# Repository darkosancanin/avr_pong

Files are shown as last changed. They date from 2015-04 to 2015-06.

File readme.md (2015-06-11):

### Overview 
ATmega328 based implementation of the classic game PONG with hardware design. The implementation of the game is a one player game with the ability to choose the skill level for the computer AI. The user paddle input control in hardware is done via a potentiometer with the TV and audio signal being output via a RCA connector and the video encoded using the PAL standard.

### PAL Signal Overview
- The PAL TV signal in the game is generated completely by the TVOut Arduino library (https://code.google.com/p/arduino-tvout/). The overview below is purely for the sake of learning.
- PAL (Phase Alternating Line) requires 625 scanlines to create one image on the screen.
- Not all 625 lines can be seen, some are used for sync pulses (and later for teletext etc), ~576 lines are visible.
- The picture is drawn one half at a time (thus the Alternating part in the name), all even lines are drawn first, then the next cycle will display all odd lines and so on. 
- Voltage levels are used to determine shades of between white and black it will render, black = 0.3V and white = 1V. (Color signal is generated differently, not covered here.)
- A voltage ladder is created by using a 470 Ohm and a 1K Ohm resistor to generate the two required voltage levels.
- Each scan line takes 64us (microseconds) to render. 12us sync signals, then 52us for the image signals.
- The vertical frequency is 50Hz, so the screen is updated with 50 half images per second, which is 25 full images per second. 
- See more at http://en.wikipedia.org/wiki/PAL

### Implementation Overview
- The game implementation is based on the code for the Pong game that is part of the Video Game Shield from Wayne and Layne (http://www.wayneandlayne.com/projects/video-game-shield/).
- I made it a one player game with very basic AI for the computer and added 3 skill levels to choose from.
- Other added features include: ability to pause, 'you won' or 'you lost' screens along with self promoting introduction screens.
- The user paddle changes sizes based on the skill level chosen.
- The ball direction when hit is based on where the ball hits the paddle, hitting the ball on the middle of the paddle will send it back in a straight line but hitting the far edges of the paddle will send the ball back at a much sharper angle.
- For the computer AI, the computer paddle moves one pixel closer in the direction of the ball every loop cycle but based on the skill level chosen it has a variable delay in reaction (it doesn't start moving until the ball is x pixels away from it). Another variable between skill levels is the 'loss of concentration' of the computer, basically the computer will not move its paddle every x amount of horizontal pixels that the ball moves across (implemented via the computer_loss_of_concentration_modulo_value variable).
- The TV signal generated is PAL and is purely implemented via TVOut Arduino library (https://code.google.com/p/arduino-tvout/). The resolution used is 120 x 96 pixels.
- The user paddle position is controlled by a analog to digital conversion reading from a 10K Ohm potentiometer.

### Schematic
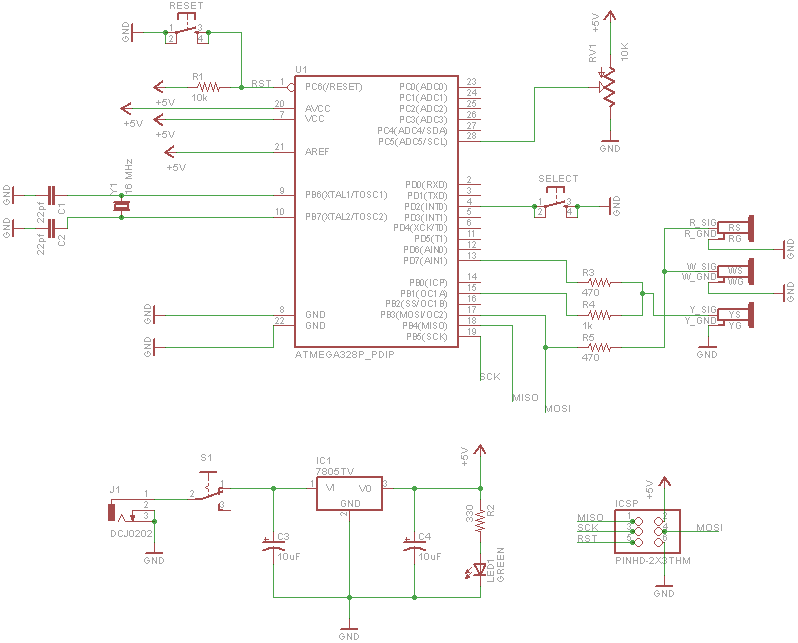
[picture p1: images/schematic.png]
Schematic


### Breadboard
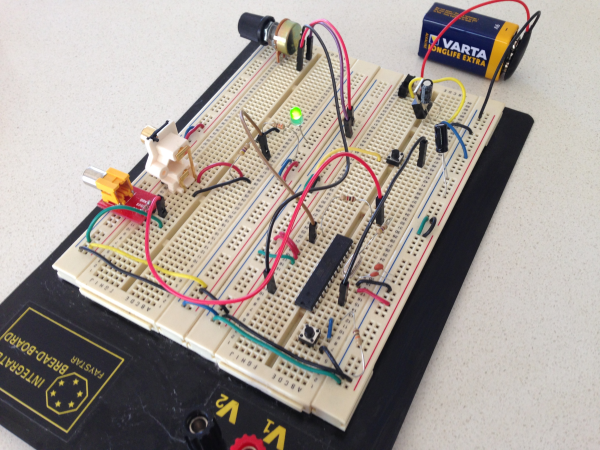
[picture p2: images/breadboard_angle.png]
Angled View


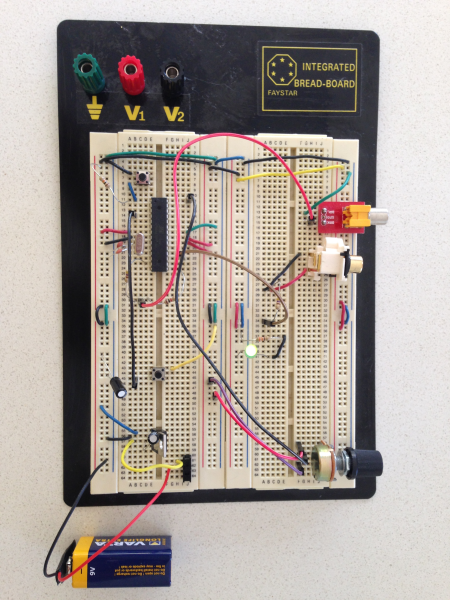
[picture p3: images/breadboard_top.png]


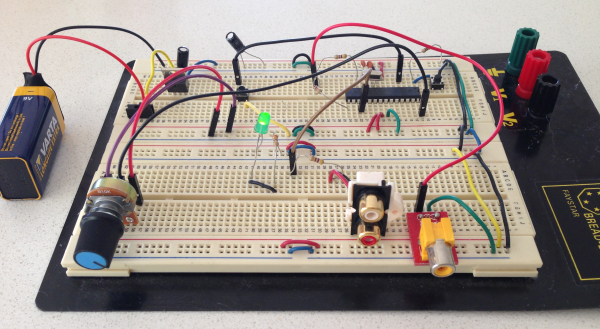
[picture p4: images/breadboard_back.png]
Back View


### TV
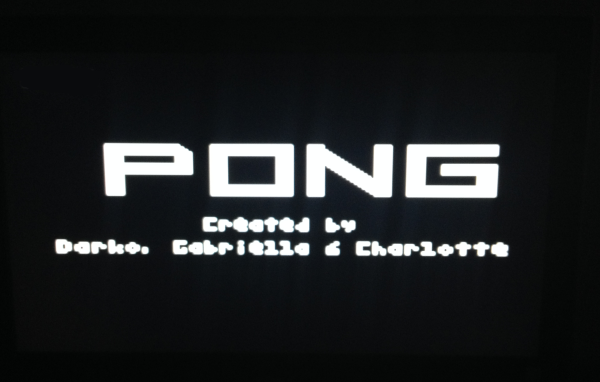
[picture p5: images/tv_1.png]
Introduction Screen


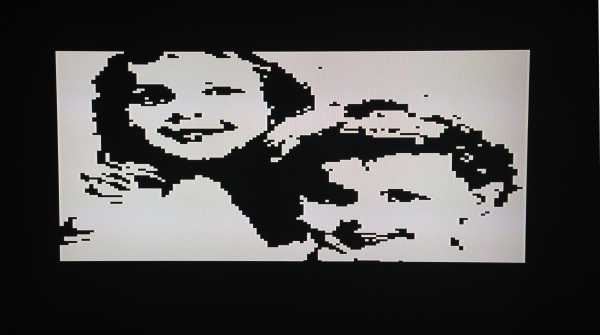
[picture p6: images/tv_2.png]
Introduction Screen Two


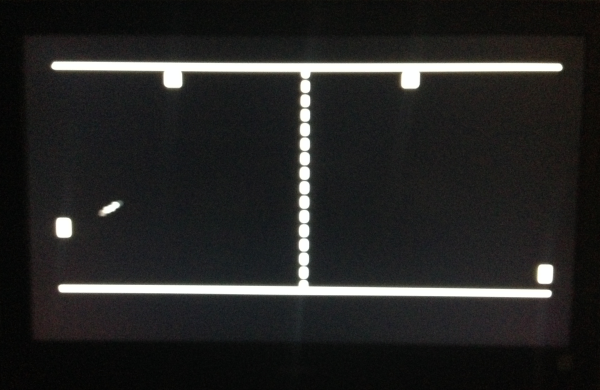
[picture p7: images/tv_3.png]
Game Play


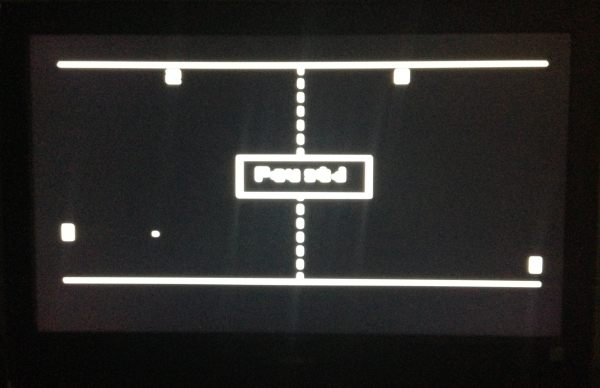
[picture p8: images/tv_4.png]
Paused Screen


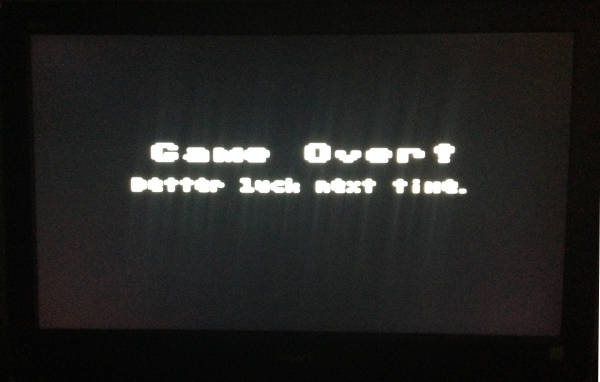
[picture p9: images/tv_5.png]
Game Over Screen


### PCB Layout
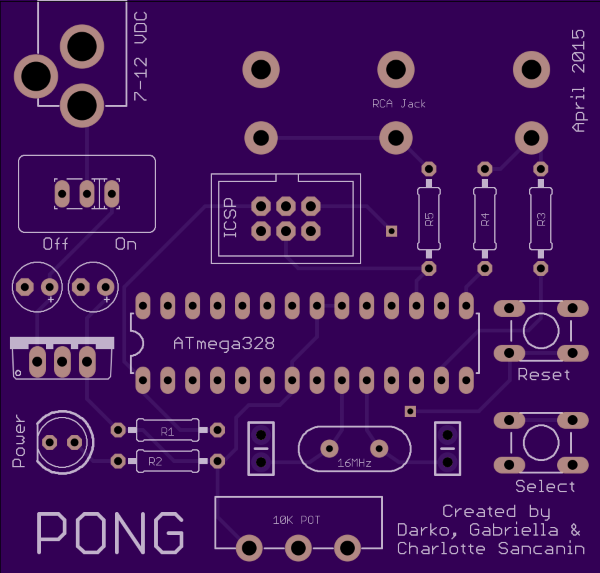
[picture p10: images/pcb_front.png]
Top


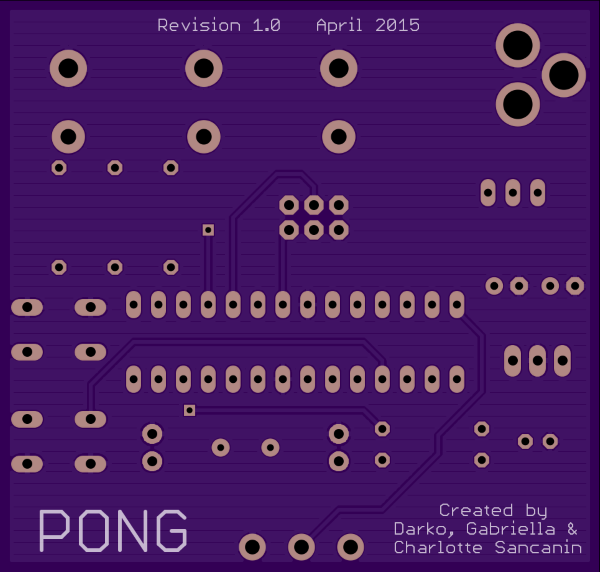
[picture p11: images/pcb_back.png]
Bottom


### Final Product
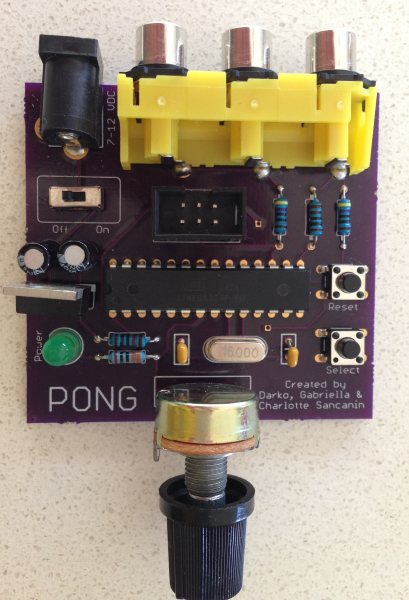
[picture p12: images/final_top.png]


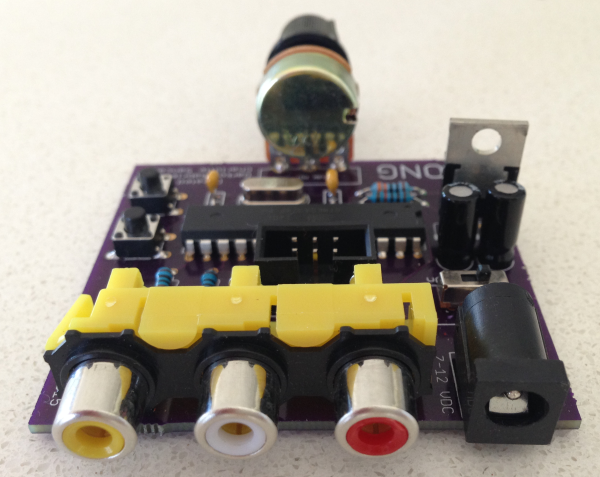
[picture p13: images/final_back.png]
Back View


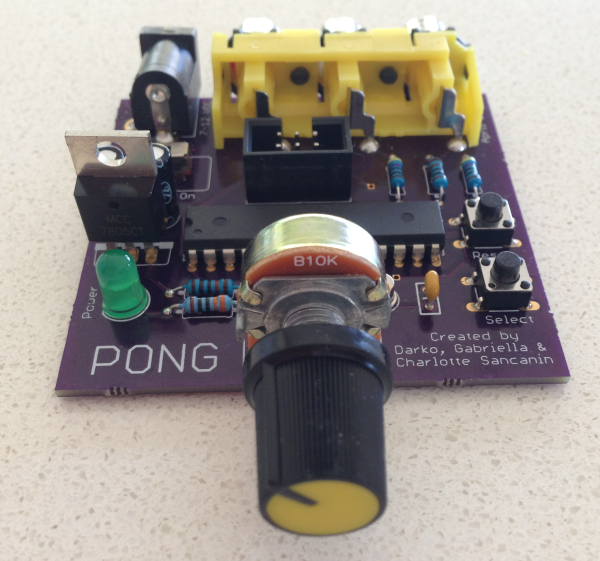
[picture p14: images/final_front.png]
Front View


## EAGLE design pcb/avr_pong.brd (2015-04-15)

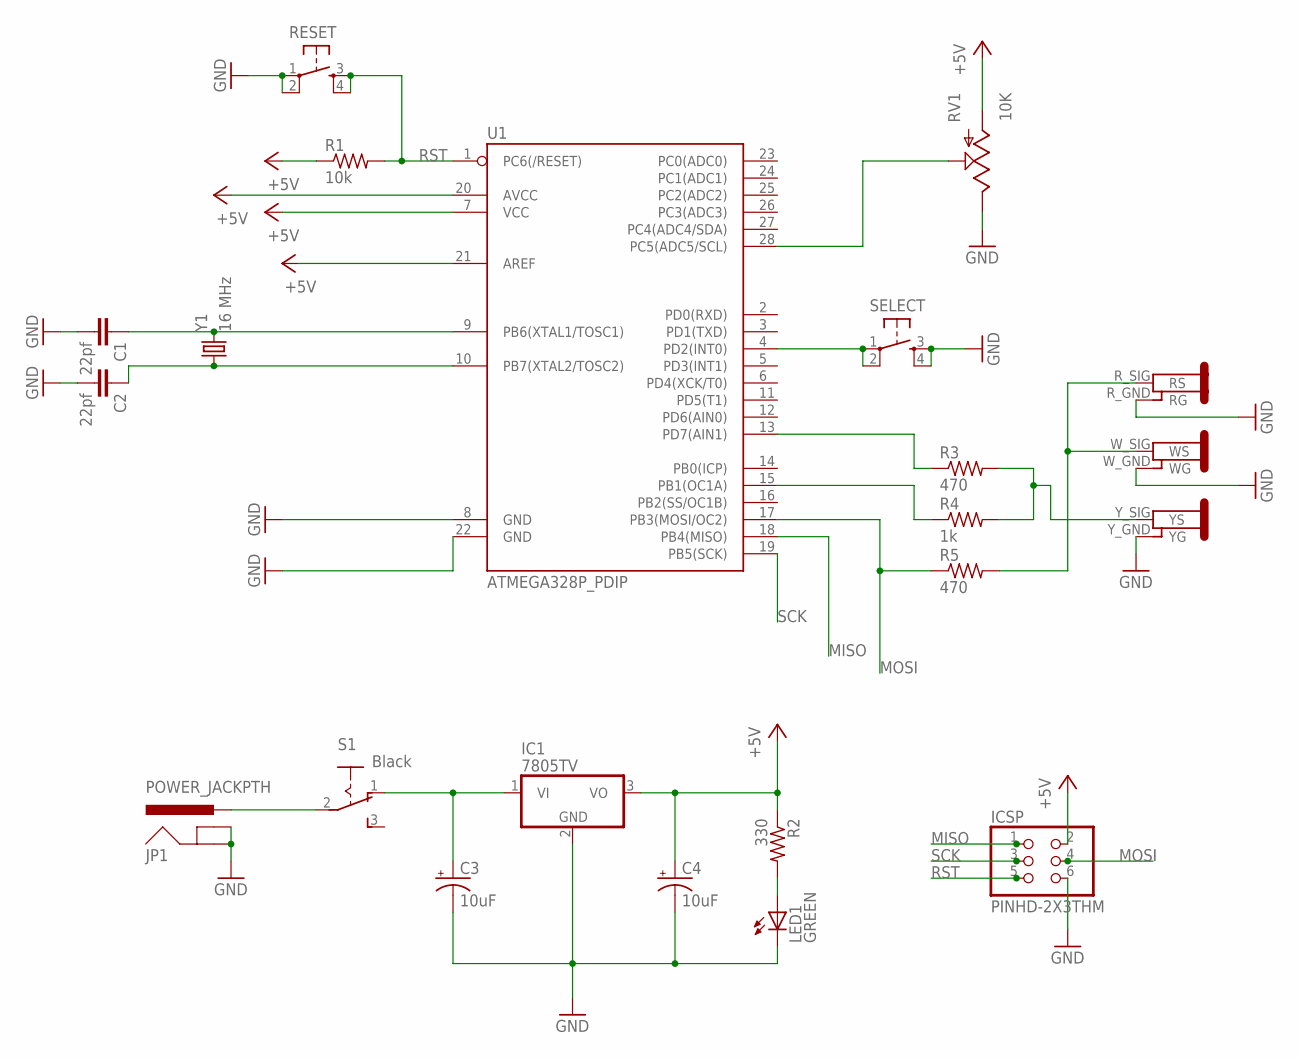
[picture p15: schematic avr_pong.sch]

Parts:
C1, C2: 22pf; CAP-PTH-SMALL-KIT
C3, C4: 10uF; E2,5-5
IC1: 7805TV; TO220V
ICSP: PINHD-2X3THM; ISP6
JP1: POWER_JACKPTH; POWER_JACK_PTH
LED1: GREEN; LED5MM
R1: 10k; 0207/10
R2: 330; 0207/10
R3, R5: 470; 0207/10
R4: 1k; 0207/10
RESET: TACTILE-SWITCH-PTH; TAC-SWITCH-PTH
RV1: 10K; POT_ALPHA_RV16AF-20
S1: Black; M251
SELECT: TACTILE-SWITCH-PTH; TAC-SWITCH-PTH
U1: ATMEGA328P_PDIP; DIL28-3
U$1: 3-RCA-JACK
Y1: 16 MHz; HC49US

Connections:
+5V: C4.+, IC1.3 (VO), ICSP.2, R1.1, R2.1, RV1.1 (A), U1.7 (VCC), U1.20 (AVCC), U1.21 (AREF)
GND: C1.2, C2.2, C3.-, C4.-, IC1.2 (GND), ICSP.6, JP1.GND, JP1.GNDBREAK, LED1.K (C), RESET.1, RESET.2, RV1.3 (E), SELECT.3, SELECT.4, U1.8 (GND), U1.22 (GND), U$1.R_GND (RG), U$1.W_GND (WG), U$1.Y_GND (YG)
MISO: ICSP.1, U1.18 (PB4(MISO))
MOSI: ICSP.4, R5.1, U1.17 (PB3(MOSI/OC2))
unnamed: C1.1, U1.9 (PB6(XTAL1/TOSC1)), Y1.2
unnamed: C2.1, U1.10 (PB7(XTAL2/TOSC2)), Y1.1
unnamed: R5.2, U$1.R_SIG (RS), U$1.W_SIG (WS)
unnamed: LED1.A, R2.2
unnamed: C3.+, IC1.1 (VI), S1.1 (O)
unnamed: JP1.PWR, S1.2
unnamed: RV1.2 (S), U1.28 (PC5(ADC5/SCL))
unnamed: SELECT.1, SELECT.2, U1.4 (PD2(INT0))
unnamed: R3.1, U1.13 (PD7(AIN1))
unnamed: R4.1, U1.15 (PB1(OC1A))
unnamed: R3.2, R4.2, U$1.Y_SIG (YS)
RST: ICSP.5, R1.2, RESET.3, RESET.4, U1.1 (PC6(/RESET))
SCK: ICSP.3, U1.19 (PB5(SCK))

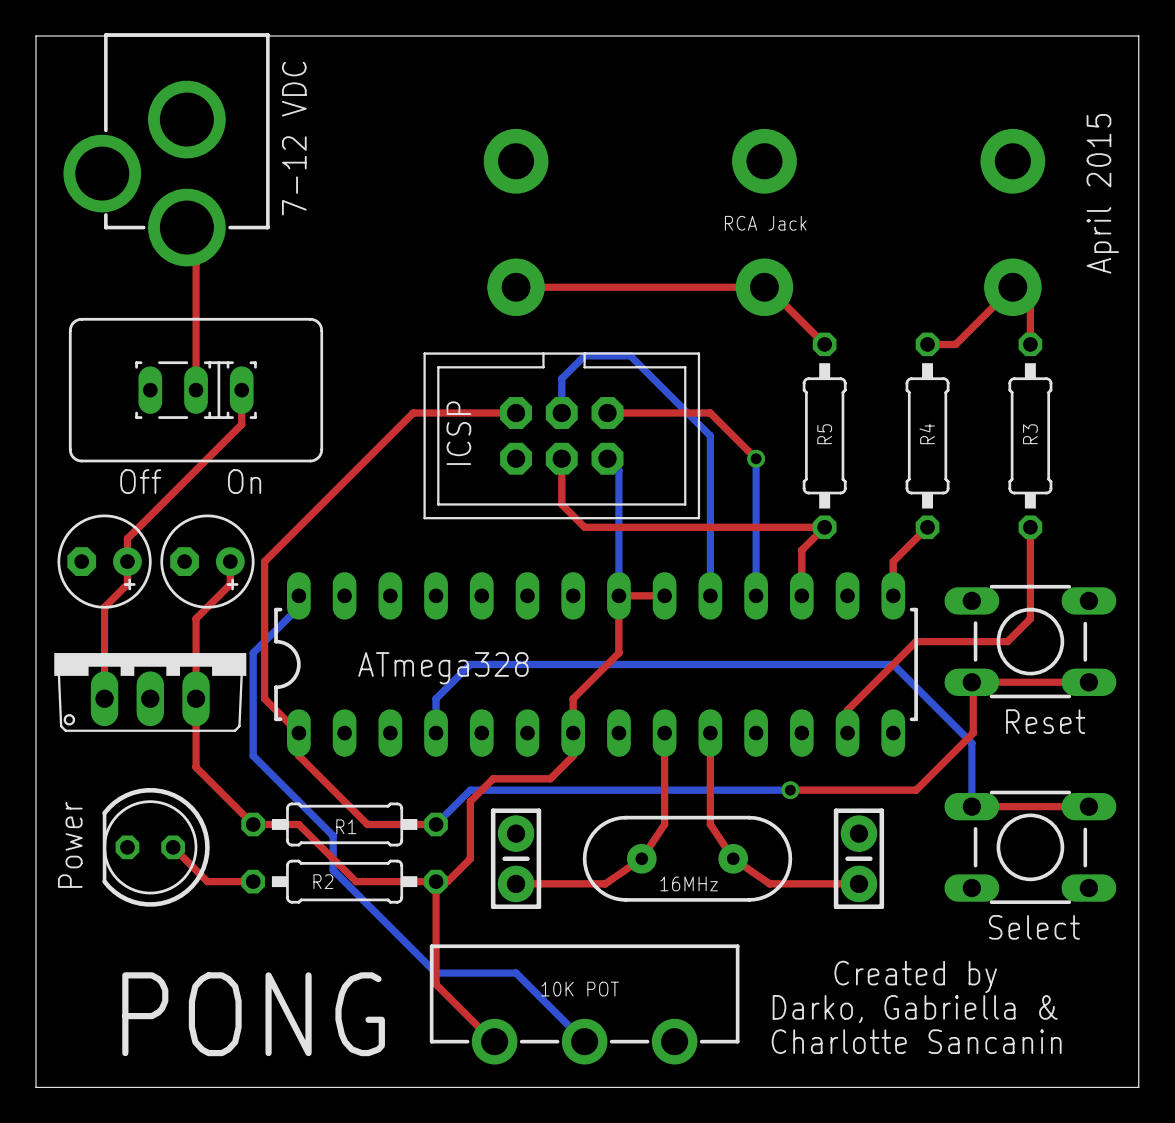
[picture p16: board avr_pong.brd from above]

Board: 2 copper layers, 61.3 x 58.4 mm, 20 parts (0 on the bottom side), 17 nets.

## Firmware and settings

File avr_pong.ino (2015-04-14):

#include <TVout.h>
#include <avr/pgmspace.h>
#include <fontALL.h>
#include "pong_logo.h"
#include "gabriella_and_charlotte.h"

#define PLAY_BEEP_SOUND TV.tone(2000, 30)
#define PLAY_MISS_SOUND TV.tone(500, 30)
#define PADDLE_BUFFER 2
#define PADDLE_WIDTH 2
#define TOP_AND_BOTTOM_LINE_HEIGHT 1
#define SKILL_LEVEL_EASY 1
#define SKILL_LEVEL_MEDIUM 2
#define SKILL_LEVEL_HARD 3
#define MODE_INTRODUCTION_SCREEN_ONE 0
#define MODE_INTRODUCTION_SCREEN_TWO 1
#define MODE_CHOOSE_SKILL_LEVEL 2
#define MODE_PLAY 3
#define MODE_PAUSE 4
#define MODE_GAME_FINISHED 5

// The following variables store general settings
volatile unsigned long select_button_last_pressed_time = 0; // Stores when the select button was last pressed
volatile char mode = MODE_INTRODUCTION_SCREEN_ONE; // Stores the current mode, its values are one of the predefined MODE_xxx values
byte horizontal_resolution, vertical_resolution; // Stores the horizontal and vertical resolution being displayed
TVout TV;

// The following variables store the computer skill level settings
int skill_level = SKILL_LEVEL_EASY; // Stores the game skill level, its values are one of the predefined SKILL_LEVEL_xxx values
byte paddle_height; // Stores the height of the paddles, the height gets smaller and smaller based on the skill level
byte computer_reaction_delay; // Stores the reaction time of the computer
byte computer_loss_of_concentration_modulo_value; // The computer ignores the movement of the ball if the ball_x_position mod this value is 0
byte game_update_frame_delay = 1; // Sets the delay time between frames. The higher the delay the slower the game play.

// The following variables store game play values
byte ball_x_position, ball_y_position; // Stores the current position of the ball in the respective coordinate plane
char ball_x_direction = 1; // Stores the direction the ball is currently heading in the x coordinate (1 = right, -1 = left)
char ball_y_direction = 1; // Stores the direction the ball is currently heading in the y coordinate (1 = up, -1 = down)
byte score[] = {0, 0}; // Stores the current scores for computer and user respectively
byte leftpaddle_y, rightpaddle_y; // Stores the y position of the paddles
byte ball_is_covering_white_area = 0; // Stores whether the ball is currently over a existing white area such as text or the middle line
byte who_served_last = 0; // Stores who served last, the serving rotates each game
byte min_ball_y_position = TOP_AND_BOTTOM_LINE_HEIGHT; // The min position is when it hits the top white line 
byte max_ball_y_position; // The max position is when it hits the bottom white line 
byte min_ball_x_position = PADDLE_WIDTH; // The min position is when it hits the left paddle 
byte max_ball_x_position; // The max position is when it hits the right paddle

void setup()
{
  digitalWrite(2, HIGH); 
  attachInterrupt(0, select_button_pressed, FALLING);
  TV.begin(PAL, 120, 96);
  TV.select_font(font4x6);
  horizontal_resolution = TV.hres() - 2; // Default resolution is not visible on all TV's
  vertical_resolution = TV.vres() - 2;
  max_ball_y_position = vertical_resolution - TOP_AND_BOTTOM_LINE_HEIGHT; // The max position is when it hits the bottom white line 
  max_ball_x_position = horizontal_resolution - PADDLE_WIDTH - 1; // The max position is when it hits the right paddle which is two pixels
  start();
}

void start()
{
  display_introduction_screens();
  display_choose_skill_level_screen();  
  reset_scores();
  reset_game();
}

void display_introduction_screens()
{
  mode = MODE_INTRODUCTION_SCREEN_ONE;
  TV.clear_screen();
  TV.bitmap(16, 26, pong_logo);
  TV.println(40, 57, "Created by");
  TV.println(4, 67, "Darko, Gabriella & Charlotte");
  wait_for_period_or_until_mode_changed(3000, MODE_INTRODUCTION_SCREEN_ONE);
  mode = MODE_INTRODUCTION_SCREEN_TWO;
  TV.bitmap(0,0, gabriella_and_charlotte);
  wait_for_period_or_until_mode_changed(3000, MODE_INTRODUCTION_SCREEN_TWO);
}

void wait_for_period_or_until_mode_changed(int wait_period, char current_mode)
{
  unsigned int startMillis = millis();
  while(((millis() - startMillis) <= wait_period) && mode == current_mode) {}
}

void display_choose_skill_level_screen()
{
  mode = MODE_CHOOSE_SKILL_LEVEL;
  TV.clear_screen();
  TV.select_font(font6x8);
  TV.println(6, 10, "Choose Skill Level");
  TV.select_font(font4x6);
  TV.println(50, 40, "Easy");
  TV.println(50, 55, "Medium");
  TV.println(50, 70, "Hard");
  // Display for n seconds or until the select button is pressed which changes the mode 
  unsigned int startMillis = millis();
  while(((millis() - startMillis) <= 3000) && mode == MODE_CHOOSE_SKILL_LEVEL) 
  {
    int paddle_analog_position_value = analogRead(5);
    TV.draw_rect(43, 40, 2, 40, 0, 0); // Clear all possible selections
    // Draw the selection rectangle for the skill level they chose and set the computer skill variable settings
    if(paddle_analog_position_value >=0 && paddle_analog_position_value < 341)
    {
      skill_level = SKILL_LEVEL_EASY;
      TV.draw_rect(43, 40, 2, 5, 1, 1);
      paddle_height = 9;
      computer_reaction_delay = 70;
      computer_loss_of_concentration_modulo_value = 10;
      game_update_frame_delay = 2;
    }
    else if(paddle_analog_position_value >= 341 && paddle_analog_position_value < 682)
    {
      skill_level = SKILL_LEVEL_MEDIUM;
      TV.draw_rect(43, 55, 2, 5, 1, 1);
      paddle_height = 7;
      computer_reaction_delay = 20;
      computer_loss_of_concentration_modulo_value = 15;
      game_update_frame_delay = 1;
    }
    else
    {
      skill_level = SKILL_LEVEL_HARD;
      TV.draw_rect(43, 70, 2, 5, 1, 1);
      paddle_height = 5;
      computer_reaction_delay = 0;
      computer_loss_of_concentration_modulo_value = 0;
      game_update_frame_delay = 1;
    }
    TV.delay_frame(1);
  }
  mode = MODE_PLAY;
  TV.clear_screen();
}

void reset_scores()
{
  score[0] = 0;
  score[1] = 0; 
}

void redraw_paddles()
{
  // Clear old paddles by drawing 1 pixel black line down each side of the screen
  TV.draw_rect(0, 1, 1, vertical_resolution - 2, 0, 0);
  TV.draw_rect(horizontal_resolution-2, 1, 1, vertical_resolution - 2, 0, 0);
  
  // Draw the paddles, which are 1 pixel wide (and PADDLE_HEIGHT high) on each side of the screen
  TV.draw_rect(0, leftpaddle_y, 1, paddle_height, 1, 1);
  TV.draw_rect(horizontal_resolution-2, rightpaddle_y, 1, paddle_height, 1, 1);
}

void redraw_vertical_middle_line(){
  // Draw the dotted vertical middle line
  for (byte y = 1; y < vertical_resolution - 1; y += 6)
    TV.draw_line(horizontal_resolution / 2, y, horizontal_resolution / 2, y + 2, 1);
}

void reset_game()
{
  TV.clear_screen();
  
  TV.draw_line(0, 0, horizontal_resolution, 0, 1); // Draw the top line
  TV.draw_line(0, vertical_resolution, horizontal_resolution, vertical_resolution, 1); // Draw the bottom line
  
  redraw_vertical_middle_line();
  
  // Update the scores
  TV.print_char((horizontal_resolution / 4) - 4, 3, '0' + score[0]); // Draw the computer (left side) score
  TV.print_char((horizontal_resolution / 4) + (horizontal_resolution / 2) - 4, 3, '0' + score[1]); // Draw the user (right side) score
  
  byte noise = analogRead(2); // Grab a random value from one of the analog pins
  
  // Randomize the ball position and direction
  ball_y_position = (noise & 0x10) ? ((noise & 0x20) ? vertical_resolution/4 : (vertical_resolution/4 + vertical_resolution/2)) : vertical_resolution / 2;
  ball_y_direction = (noise & 0x02) ? -1 :  1;
  ball_x_position = (who_served_last) ?  min_ball_x_position : max_ball_x_position;
  ball_x_direction = (who_served_last) ?  1 : -1;
  who_served_last = who_served_last ? 0 : 1;
  
  redraw_paddles();
}

void display_you_won_screen()
{
  mode = MODE_GAME_FINISHED;
  TV.clear_screen();
  TV.select_font(font8x8);
  TV.println(28, 34, "You Won!");
  TV.select_font(font4x6);
  TV.println(40, 50, "Well done.");
  // Display for n seconds or until the select button is pressed which changes the mode 
  wait_for_period_or_until_mode_changed(3000, MODE_GAME_FINISHED);
  mode = MODE_PLAY;
}

void display_game_over_screen()
{
  mode = MODE_GAME_FINISHED;
  TV.clear_screen();
  TV.select_font(font8x8);
  TV.println(20, 34, "Game Over!");
  TV.select_font(font4x6);
  TV.println(16, 50, "Better luck next time.");
  // Display for n seconds or until the select button is pressed which changes the mode 
  wait_for_period_or_until_mode_changed(3000, MODE_GAME_FINISHED);
  mode = MODE_PLAY;
}

void player_won_a_point(byte player_who_won)
{ 
  score[player_who_won]++; // Increase the score of the winner
  TV.printPGM((player_who_won) ? (11) : (horizontal_resolution - 39), (vertical_resolution / 2) - 4, PSTR("Missed!"));
  TV.printPGM((player_who_won) ? (horizontal_resolution - 39) : (11), (vertical_resolution / 2) - 4, PSTR("Winner!"));
  PLAY_MISS_SOUND;
  redraw_ball();
  wait_for_period_or_until_mode_changed(1000, MODE_PLAY);
    
  if (score[player_who_won] == 5) // Check if the winner of the point won the game
  {
    if(player_who_won == 1){
      display_you_won_screen();
    }
    else
    {
      display_game_over_screen(); 
    }
    reset_scores();
  }

  reset_game();
}

void updateComputerPaddle()
{
  if (ball_x_direction == 1) return; // Don't track the ball when its heading towards the user
  if (ball_x_position > (horizontal_resolution - computer_reaction_delay)) return; // Don't track the ball if its within its reaction delay
  if (ball_x_position % computer_loss_of_concentration_modulo_value == 0) return; // Ignore the ball movement every so many movements
    
  // Move the computer paddle up or down if the ball is above or below the middle of the paddle
  if (ball_y_position > (leftpaddle_y + (paddle_height / 2)) && leftpaddle_y < (vertical_resolution - paddle_height))
  {
    leftpaddle_y++;
  }
  else if (ball_y_position < (leftpaddle_y + (paddle_height / 2)) && leftpaddle_y > 0)
  {
    leftpaddle_y--;
  }
}

// This method changes the direction of the ball based on where the ball is hit on the paddle.
// If it hits directly in the center then the angle is straight back (0), if its right at the edges
// then the angle is -2 or 2 and the other angle is -1 or 1.
void change_y_direction_of_ball(byte ball_y_position, byte paddle_y_position)
{  
  char distance_of_ball_from_center_of_paddle = ball_y_position - (paddle_y_position + ((paddle_height + 1) / 2));
  if(distance_of_ball_from_center_of_paddle == 0) ball_y_direction = 0;
  if(skill_level == SKILL_LEVEL_EASY){
    if(distance_of_ball_from_center_of_paddle == 0) 
      ball_y_direction = 0;
    else if(distance_of_ball_from_center_of_paddle < -3) 
      ball_y_direction = -2;
    else if(distance_of_ball_from_center_of_paddle < 0) 
      ball_y_direction = -1;
    else if(distance_of_ball_from_center_of_paddle > 3) 
      ball_y_direction = 2;
    else if(distance_of_ball_from_center_of_paddle > 0) 
      ball_y_direction = 1;
  }
  else if(skill_level == SKILL_LEVEL_MEDIUM){
    if(distance_of_ball_from_center_of_paddle == 0) 
      ball_y_direction = 0;
    else if(distance_of_ball_from_center_of_paddle < -2) 
      ball_y_direction = -2;
    else if(distance_of_ball_from_center_of_paddle < 0) 
      ball_y_direction = -1;
    else if(distance_of_ball_from_center_of_paddle > 2) 
      ball_y_direction = 2;
    else if(distance_of_ball_from_center_of_paddle > 0) 
      ball_y_direction = 1;
  }
  else if(skill_level == SKILL_LEVEL_HARD){
    if(distance_of_ball_from_center_of_paddle == 0) 
      ball_y_direction = (ball_y_position % 2) ? 1 : -1;
    else if(distance_of_ball_from_center_of_paddle < -1) 
      ball_y_direction = -2;
    else if(distance_of_ball_from_center_of_paddle < 0) 
      ball_y_direction = -1;
    else if(distance_of_ball_from_center_of_paddle > 1) 
      ball_y_direction = 2;
    else if(distance_of_ball_from_center_of_paddle > 0) 
      ball_y_direction = 1;
  }
}

void redraw_ball()
{
  if(ball_is_covering_white_area == 0)
  {
    TV.set_pixel(ball_x_position, ball_y_position, 0); // Set the previous ball position to be black
  }
  ball_x_position += ball_x_direction;
  ball_y_position += ball_y_direction;
  if(TV.get_pixel(ball_x_position, ball_y_position) == 1){
    ball_is_covering_white_area = 1;
  }
  else{
    ball_is_covering_white_area = 0;  
    TV.set_pixel(ball_x_position, ball_y_position, 1); // Draw the white ball on the screen
  }
}

void display_pause_screen(){
  TV.draw_rect(43, 40, 34, 16, 1, 0);
  TV.printPGM(48, 45, PSTR("Paused"));
  // Display until the select button is pressed which changes the mode back to MODE_PLAY
  while(mode == MODE_PAUSE) {}
  TV.draw_rect(43, 40, 34, 16, 0, 0);
  redraw_vertical_middle_line();
  redraw_ball();
}

void update_game_play()
{
  // Read in the user paddle position from the potentiometer
  rightpaddle_y = map(analogRead(5), 0, 1024, 1, vertical_resolution - paddle_height); 
  updateComputerPaddle();
  
  redraw_paddles();
  redraw_ball();
  
  if (ball_x_position == min_ball_x_position) // Check if it hit the computer paddle
  {
    if (ball_y_position > leftpaddle_y - PADDLE_BUFFER && ball_y_position < (leftpaddle_y + paddle_height + PADDLE_BUFFER) && ball_x_direction < 0 )
    {
      PLAY_BEEP_SOUND;
      change_y_direction_of_ball(ball_y_position, leftpaddle_y);
      ball_x_direction = 1; 
    }
  }
  else if (ball_x_position == max_ball_x_position)  // Check if it hit the user paddle
  {
    if (ball_y_position > rightpaddle_y - PADDLE_BUFFER && ball_y_position < (rightpaddle_y + paddle_height + PADDLE_BUFFER) && ball_x_direction > 0 )
    {
      PLAY_BEEP_SOUND;
      change_y_direction_of_ball(ball_y_position, rightpaddle_y);  
      ball_x_direction = -1; 
    }
  }
  else if (ball_x_position < min_ball_x_position) // Check if it hit the left wall
  {
    player_won_a_point(1);
    return;
  }
  else if (ball_x_position > max_ball_x_position) // Check if it hit the right wall
  {
    player_won_a_point(0);
    return;
  }
  
  // Check if ball hit the top or bottom of the screen
  if (ball_y_position >= max_ball_y_position || ball_y_position <= min_ball_y_position)
  {
    PLAY_BEEP_SOUND;
    ball_y_direction *= -1;
  }

  TV.delay_frame(game_update_frame_delay);
}

void loop()
{ 
  if(mode == MODE_PLAY)
    update_game_play();
  else if(mode == MODE_PAUSE)
    display_pause_screen();
}

// Interrupt handler for the select button 
void select_button_pressed()
{
  unsigned long current_millis = millis();
  // Ignore the button press if its with the debounce delay time (120ms) from its last press
  if ((current_millis - select_button_last_pressed_time) > 120) {
    if(mode == MODE_INTRODUCTION_SCREEN_ONE)
      mode = MODE_INTRODUCTION_SCREEN_TWO;
    else if(mode == MODE_INTRODUCTION_SCREEN_TWO)
      mode = MODE_CHOOSE_SKILL_LEVEL;
    else if(mode == MODE_CHOOSE_SKILL_LEVEL || mode == MODE_PAUSE || mode == MODE_GAME_FINISHED)
      mode = MODE_PLAY;
    else if(mode == MODE_PLAY)
      mode = MODE_PAUSE;
    select_button_last_pressed_time = millis();
  }
}

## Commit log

2015-03-30 Select button implementation.
2015-03-30 Added start of schematic.
    [avr_pong.sch]
2015-04-04 Removed sleep code as it will be powered by a DC jack and regulator.
2015-04-04 Added skip per introduction screen.
    [avr_pong.ino]
2015-04-06 Updated schematic.
    [avr_pong.sch]
2015-04-14 Updated schematic and added board layout.
    [avr_pong.brd, avr_pong.sch]
2015-04-14 Updated board layout.
    [avr_pong.brd]
2015-04-15 Added PCB layout.
    [avr_pong.brd, avr_pong.sch]
2015-05-17 Renamed file to lower case.

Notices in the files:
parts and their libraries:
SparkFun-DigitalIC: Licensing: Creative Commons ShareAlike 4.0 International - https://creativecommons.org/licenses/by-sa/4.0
